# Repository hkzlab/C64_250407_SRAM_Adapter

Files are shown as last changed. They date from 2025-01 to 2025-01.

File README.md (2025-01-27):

# C64 ASSY 250407 SRAM Adapter

## DISCLAIMER

Any use of this project is **under your own responsibility**.
You will be responsible of checking the correct construction and functionality of your board.
By using this project You will agree that I cannot be held responsible if it will destroy any of your devices, damage your computer, burn down your house or whatever.

**WARNING**: This is compatible with the 250407 board only!!!

## Introduction

This board implements a static RAM replacement for the DRAMs on a C64 with a 250407 motherboard.
I wanted to both reduce power consumption, and get a fix for the [VSP bug](https://www.pouet.net/prod.php?which=61024#c637759).

You will have to socket your DRAM ICs to install this board.

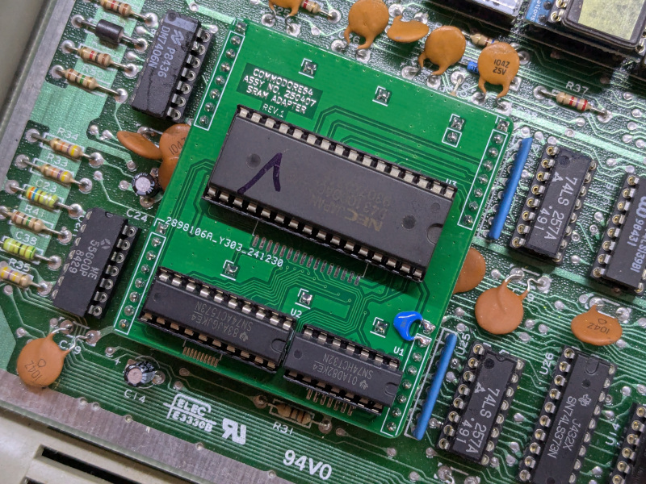
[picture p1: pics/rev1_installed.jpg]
Rev. 1 board installed in a C64


### Ordering the boards

You can order the board for this project at [PCBWay](https://www.pcbway.com/project/shareproject/C64_250407_SRAM_Adapter_9502264b.html) and support me or download 
the gerbers and have them printed wherever you like!!!

## Features

- You can choose to use SMD or DIP components for the logic and memory ICs
- Once the DRAMs are socketed, the board is easy to plug in and remove
- If your C64 lacks C203, a capacitor can be fitted on this board without having to further modify your motherboard

## Hardware

The board was designed with [KiCad](https://kicad.org/) EDA.

### Bill of Materials

| Component | Qty | Type / Value | Notes |
| --- | --- | --- | --- |
| C1, C2, C3 |  3  | 100nF ceramic cap, SMD 1206 | Decoupling caps, rated at least 10V. |
| C5 |  1  | ~82-820pF ceramic cap, THT 2.5mm | Optional, install either this or C4 if C203 on mobo is missing |
| C4 |  1  | ~82-820pF ceramic cap, SMD 1206  | Optional, install either this or C5 if C203 on mobo is missing |
| U1 |  1  | 74HCT32, DIP14 or SO14 | Can be replaced with an ACT/ALS/LS/F. Do NOT use an HC. |
| U2 |  1  | 74HCT573, DIP 20 or TSSOP20 | Can be replaced with an ACT/ALS/LS/F. Do NOT use an HC. |
| U3 |  1  | 128Kx8 SRAM, DIP32 or SOP32 | I tested ICs between 75ns to 100ns without issue. 628128 pinout. |
| Headers |  1  | 40p 2.54mm machined header strip | Cut it into 4x8p, 1x2p and 5x1p pieces, then solder on the underside |

C4/C5 adjust `/CAS` timing to make the board play nice in C64s that do not have C203 fitted.

Value of C5/C4 is non critical, I had good luck with 300pF and 100pF caps. Note that I could also make do without the cap entirely
by replacing U1 (the '32 gate) with a schottky based one, so LS/ALS/F family.

### Fixes

#### Rev. 1

Rev. 1 lacks the space to solder C4/C5, you can just bodge a cap on the first two pins (`GND` and `/CAS`) of the bottom right header.

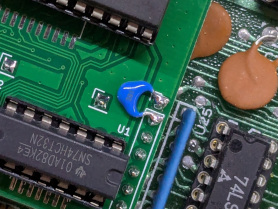
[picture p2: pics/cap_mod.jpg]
Capacaitor bodge mod on rev.1


### Known Issues

I could not detect stability issues, the only problem I found is a graphical glitch on the title screen of ZetaWing 2,
where a single lines of pixels is flickering.

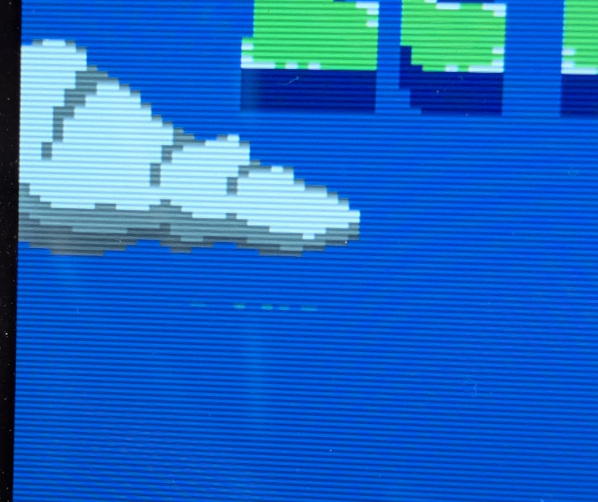
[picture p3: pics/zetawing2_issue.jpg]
ZetaWing 2 title screen


Note that this same issue **happens with other SRAM mods** (meant for shortboards) bodged to work on this machine, and disappears when using real DRAM ICs.

This seems a quirk of my VIC-II, a 6569R3. I modified the motherboard to support an 8565 and the issue disappeared (tested with an 8565R2).

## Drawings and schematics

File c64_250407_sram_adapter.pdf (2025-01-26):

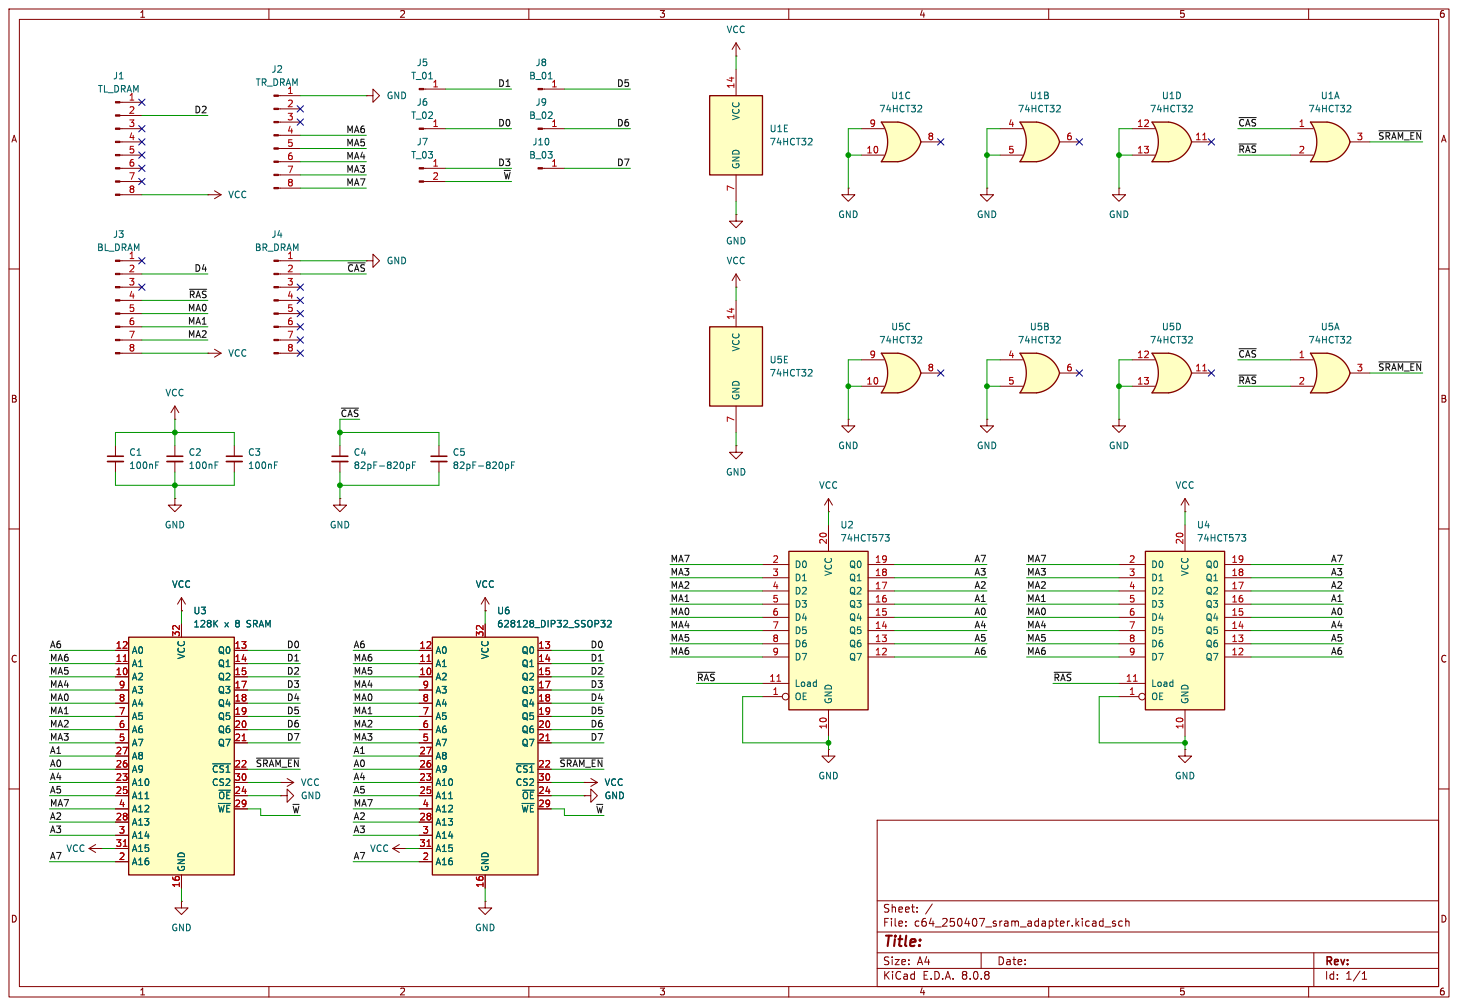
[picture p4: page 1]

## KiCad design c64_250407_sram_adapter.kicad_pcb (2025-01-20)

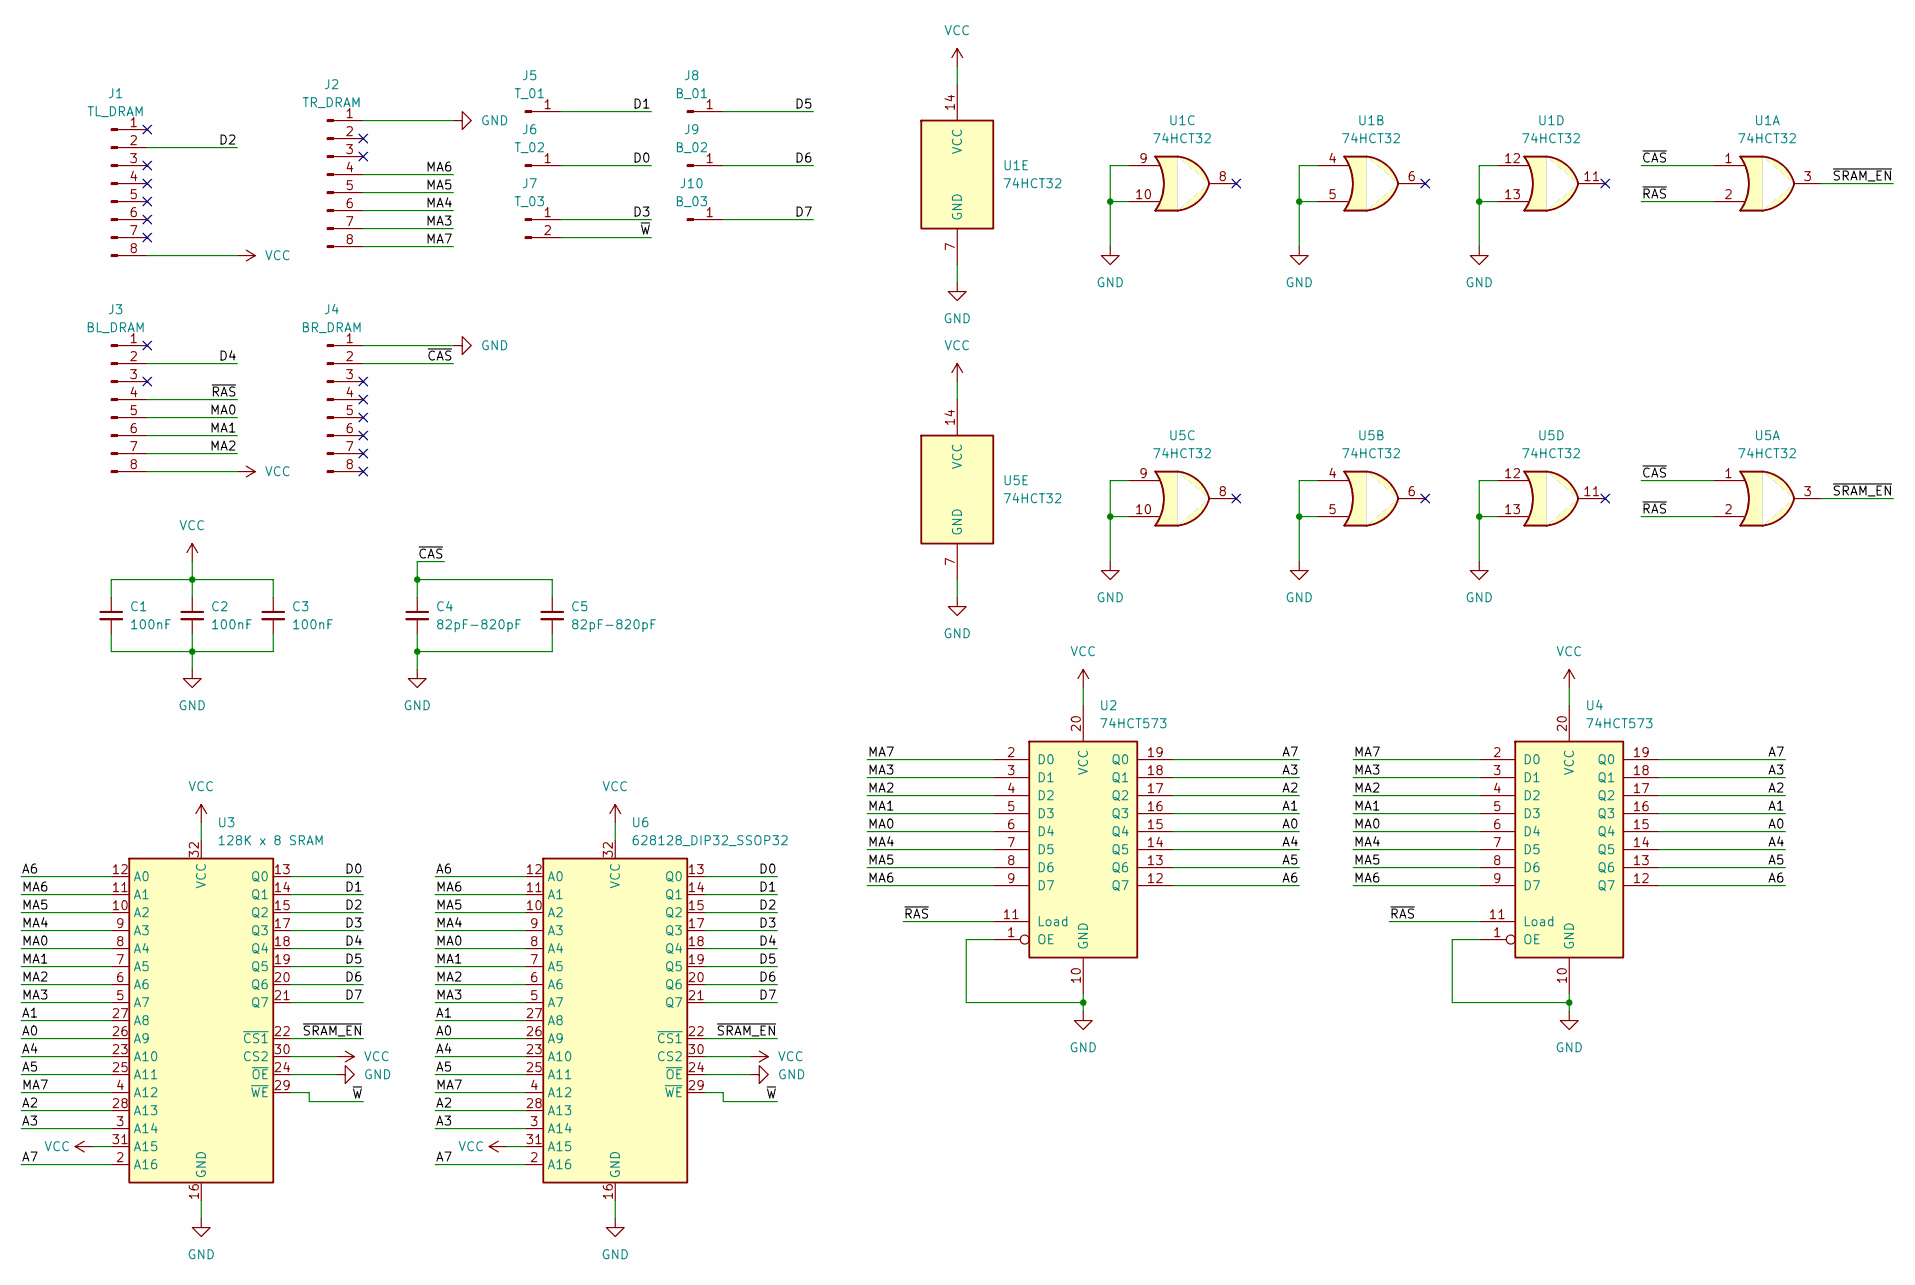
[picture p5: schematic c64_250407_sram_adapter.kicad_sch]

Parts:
C1, C2, C3: 100nF; C_1206_3216Metric_Pad1.33x1.80mm_HandSolder
C4: 82pF-820pF; C_1206_3216Metric_Pad1.33x1.80mm_HandSolder
C5: 82pF-820pF; C_Disc_D3.0mm_W2.0mm_P2.50mm
J1: TL_DRAM; PinHeader_1x08_P2.54mm_Vertical
J2: TR_DRAM; PinHeader_1x08_P2.54mm_Vertical
J3: BL_DRAM; PinHeader_1x08_P2.54mm_Vertical
J4: BR_DRAM; PinHeader_1x08_P2.54mm_Vertical
J5: T_01; PinHeader_1x01_P2.54mm_Vertical
J6: T_02; PinHeader_1x01_P2.54mm_Vertical
J7: T_03; PinHeader_1x02_P2.54mm_Vertical
J8: B_01; PinHeader_1x01_P2.54mm_Vertical
J9: B_02; PinHeader_1x01_P2.54mm_Vertical
J10: B_03; PinHeader_1x01_P2.54mm_Vertical
U1: 74HCT32; DIP-14_W7.62mm
U2: 74HCT573; DIP-20_W7.62mm
U3: 128K x 8 SRAM; DIP-32_W15.24mm
U4: 74HCT573; TSSOP-20_4.4x6.5mm_P0.65mm
U5: 74HCT32; SO-14_3.9x8.65mm_P1.27mm
U6: 628128_DIP32_SSOP32; SOP-32_11.305x20.495mm_P1.27mm

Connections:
/A0: U2.15 (Q4), U3.26 (A9), U4.15 (Q4), U6.26 (A9)
/A1: U2.16 (Q3), U3.27 (A8), U4.16 (Q3), U6.27 (A8)
/A2: U2.17 (Q2), U3.28 (A13), U4.17 (Q2), U6.28 (A13)
/A3: U2.18 (Q1), U3.3 (A14), U4.18 (Q1), U6.3 (A14)
/A4: U2.14 (Q5), U3.23 (A10), U4.14 (Q5), U6.23 (A10)
/A5: U2.13 (Q6), U3.25 (A11), U4.13 (Q6), U6.25 (A11)
/A6: U2.12 (Q7), U3.12 (A0), U4.12 (Q7), U6.12 (A0)
/A7: U2.19 (Q0), U3.2 (A16), U4.19 (Q0), U6.2 (A16)
/D0: J6.1, U3.13 (Q0), U6.13 (Q0)
/D1: J5.1, U3.14 (Q1), U6.14 (Q1)
/D2: J1.2, U3.15 (Q2), U6.15 (Q2)
/D3: J7.1, U3.17 (Q3), U6.17 (Q3)
/D4: J3.2, U3.18 (Q4), U6.18 (Q4)
/D5: J8.1, U3.19 (Q5), U6.19 (Q5)
/D6: J9.1, U3.20 (Q6), U6.20 (Q6)
/D7: J10.1, U3.21 (Q7), U6.21 (Q7)
/MA0: J3.5, U2.6 (D4), U3.8 (A4), U4.6 (D4), U6.8 (A4)
/MA1: J3.6, U2.5 (D3), U3.7 (A5), U4.5 (D3), U6.7 (A5)
/MA2: J3.7, U2.4 (D2), U3.6 (A6), U4.4 (D2), U6.6 (A6)
/MA3: J2.7, U2.3 (D1), U3.5 (A7), U4.3 (D1), U6.5 (A7)
/MA4: J2.6, U2.7 (D5), U3.9 (A3), U4.7 (D5), U6.9 (A3)
/MA5: J2.5, U2.8 (D6), U3.10 (A2), U4.8 (D6), U6.10 (A2)
/MA6: J2.4, U2.9 (D7), U3.11 (A1), U4.9 (D7), U6.11 (A1)
/MA7: J2.8, U2.2 (D0), U3.4 (A12), U4.2 (D0), U6.4 (A12)
/~CAS: C4.1, C5.1, J4.2, U1.1, U5.1
/~RAS: J3.4, U1.2, U2.11 (Load), U4.11 (Load), U5.2
/~SRAM_EN: U1.3, U3.22 (~CS1), U5.3, U6.22 (~CS1)
/~W: J7.2, U3.29 (~WE), U6.29 (~WE)
GND: C1.2, C2.2, C3.2, C4.2, C5.2, J2.1, J4.1, U1.4, U1.5, U1.7 (GND), U1.9, U1.10, U1.12, U1.13, U2.1 (OE), U2.10 (GND), U3.16 (GND), U3.24 (~OE), U4.1 (OE), U4.10 (GND), U5.4, U5.5, U5.7 (GND), U5.9, U5.10, U5.12, U5.13, U6.16 (GND), U6.24 (~OE)
VCC: C1.1, C2.1, C3.1, J1.8, J3.8, U1.14 (VCC), U2.20 (VCC), U3.30 (CS2), U3.31 (A15), U3.32 (VCC), U4.20 (VCC), U5.14 (VCC), U6.30 (CS2), U6.31 (A15), U6.32 (VCC)

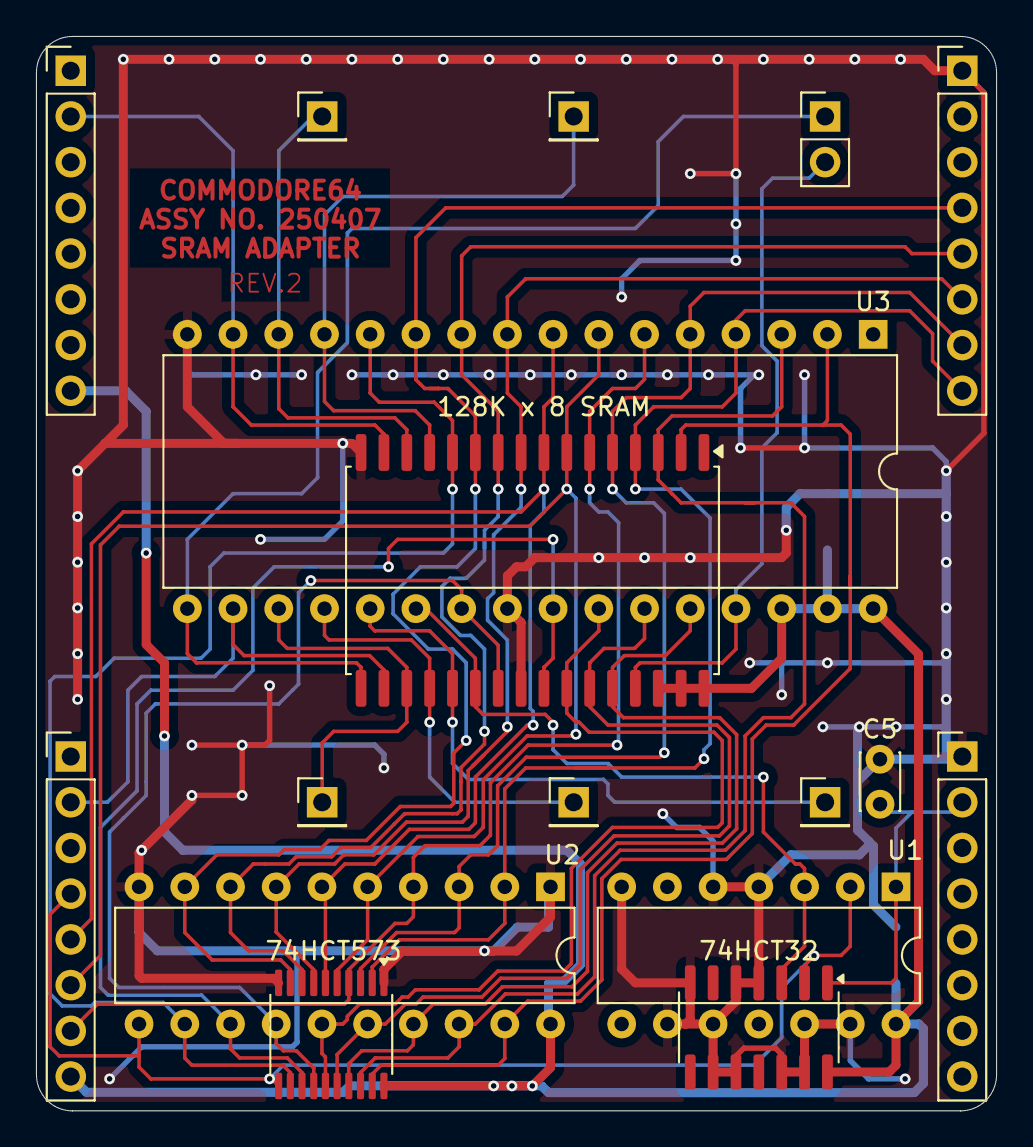
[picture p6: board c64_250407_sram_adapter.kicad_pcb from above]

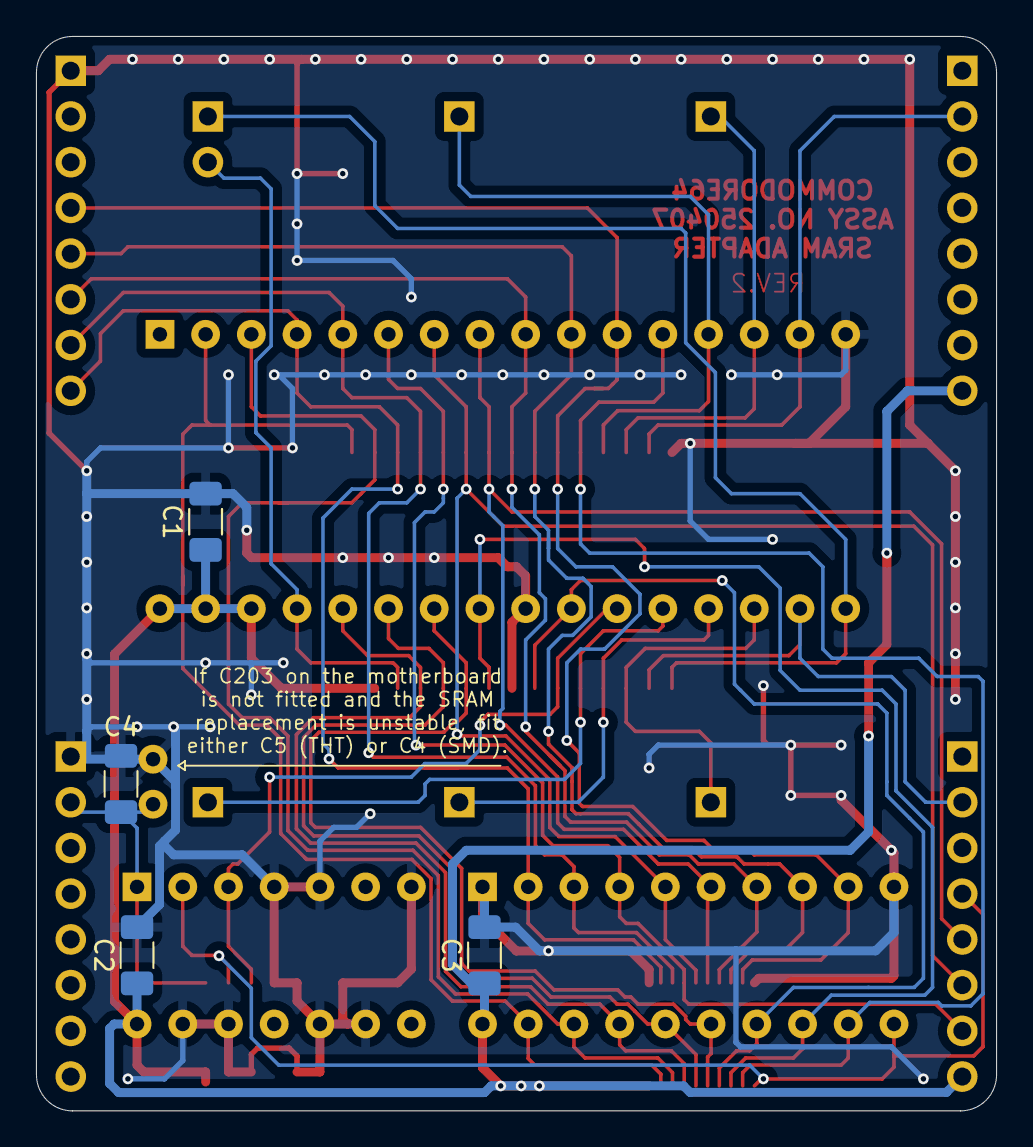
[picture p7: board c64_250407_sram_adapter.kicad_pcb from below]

Board: 2 copper layers, 53.3 x 59.7 mm, 21 parts (4 on the bottom side), 30 nets.

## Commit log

2024-12-29 Add sram converter
    [c64_250507_sram_adapter.kicad_pcb, c64_250507_sram_adapter.kicad_sch]
2024-12-29 Rev. 1 with better power trace
    [c64_250507_sram_adapter.kicad_pcb, c64_250507_sram_adapter.kicad_sch]
2024-12-29 Further tweak rev.1
    [c64_250507_sram_adapter.kicad_pcb]
2024-12-29 Remove useless measurement
    [c64_250507_sram_adapter.kicad_pcb]
2024-12-30 Rename files
    [c64_250407_sram_adapter.kicad_pcb, c64_250407_sram_adapter.kicad_sch]
2025-01-20 Updated PCB to rev.2, adding optional /CAS delay cap
    [c64_250407_sram_adapter.kicad_pcb, c64_250407_sram_adapter.kicad_sch]
2025-01-20 Fixed the silkscreen
    [c64_250407_sram_adapter.kicad_pcb, c64_250407_sram_adapter.kicad_sch]
